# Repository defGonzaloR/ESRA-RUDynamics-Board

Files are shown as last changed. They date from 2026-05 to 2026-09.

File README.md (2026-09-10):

# ESRA-RUDynamics-Board

ESRA_PDB_Gonzalo

This is V3 of the Rutgers Dynamics power distribution board, building off of the original board designed by the Columbia University Robotics team. This is also my first power distribution board design. 

I used a board-mounted XT90 connector to attach to the Lipo batteries. For circuit protection, I included fuse holders that connect to each output for the legs, as well as essential filtering for high-noise signals. At the bottom is a buck converter, to step down the 24V to 12V for powering the Jetson Orin Nano.

Due to funding, this board was discontinued, but I'm excited to apply skills and theory learned from this design to future applications.

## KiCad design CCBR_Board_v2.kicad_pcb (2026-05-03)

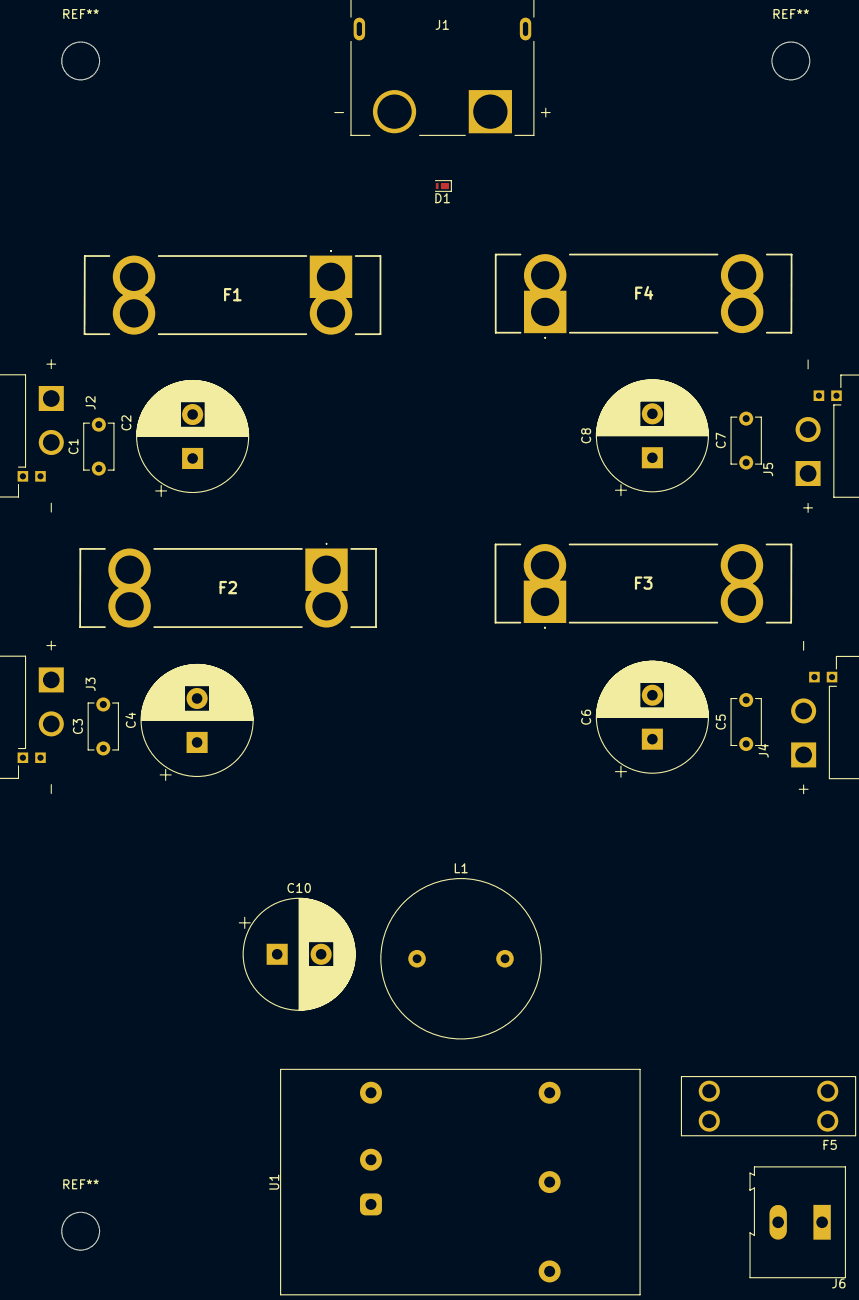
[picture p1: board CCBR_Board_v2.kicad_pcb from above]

Board: 2 copper layers, 23 parts (0 on the bottom side), 7 nets, no tracks yet.

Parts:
C1, C3, C5, C7: 0.1 uF; C_Disc_D5.1mm_W3.2mm_P5.00mm
C2, C4, C6, C8: 470 uF; CP_Radial_D12.5mm_P5.00mm
C10: 100uF; CP_Radial_D12.5mm_P5.00mm
D1: PTVS26VZ1USK; Nexperia_DSN1608-2_1.6x0.8mm
F1, F2, F3, F4: Fuse; 3581
F5: Fuse; FUSE_3557-2
J1: Conn_01x02_Pin; AMASS_XT90PW-M
J2, J3, J4, J5: Conn_01x02_Socket; AMASS_XT30PW_2_2_-M.G.B
J6: Screw_Terminal_01x02; TerminalBlock_Altech_AK300-2_P5.00mm
L1: 0.47 uH; L_Radial_D18.0mm_P10.00mm
U1: JTD1548S12; Converter_DCDC_XP_POWER_JTDxxxxxxx_THT

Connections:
+24V: C10.1, D1.1 (K), F1.2, F2.2, F3.2, F4.1, L1.1
GND: C1.2, C2.2, C3.2, C4.2, C5.2, C6.2, C7.2, C8.2, C10.2, D1.2 (A), J6.2, U1.2 (-VIN), U1.5 (-VOUT)
unnamed: C1.1, C2.1, F1.1
unnamed: C3.1, C4.1, F2.1
unnamed: C5.1, C6.1, F3.1
unnamed: C7.1, C8.1, F4.2
unnamed: L1.2, U1.1 (+VIN)
